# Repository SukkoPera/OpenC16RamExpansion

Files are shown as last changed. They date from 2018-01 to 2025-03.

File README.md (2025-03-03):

# OpenC16RamExpansion
OpenC16RamExpansion is an Open Hardware 64 Kb RAM Expansion board for the Commodore 16.

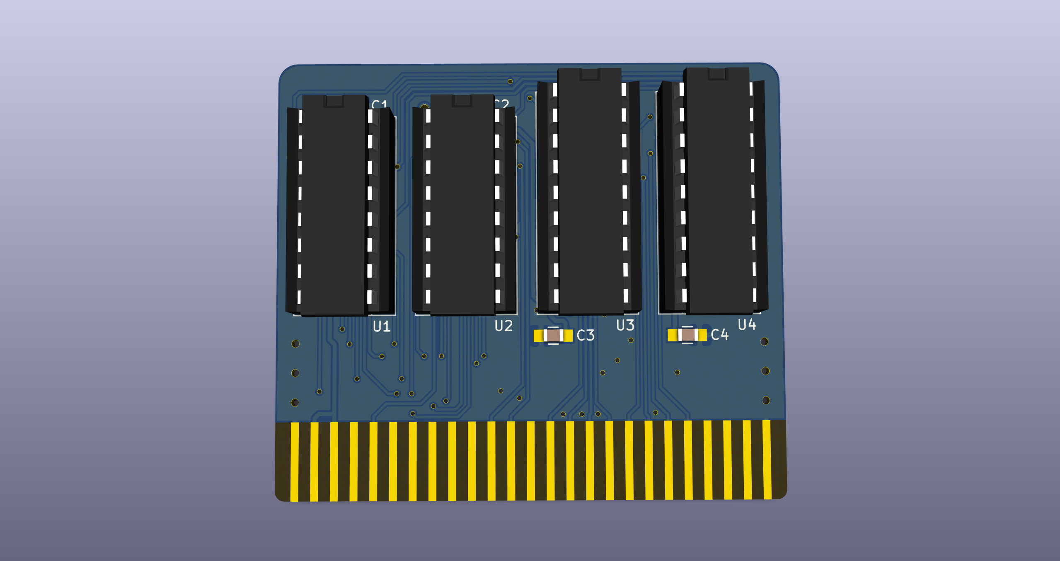
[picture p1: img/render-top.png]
Board


## Summary
The board fits the cartridge/expansion port and, in theory, it should instantly give a C16 64 kilobytes of RAM. Unfortunately, the reality is quite different since the C16 was deliberately designed not to be easily expandable, so that the larger RAM would be a selling point of the Plus/4.

This must have been a long-debated feature, since half of the job is done while the other half is missing. In particular, the /RAS, /CAS and MUX signals that are needed to control RAM chips have been brought to the cartridge slot and these cannot actually serve many other purposes. On the other hand, there is no way to disable the internal RAM when an expansion is plugged in the cartridge slot which means that both RAMs will fight for the bus, amounting to a disasterous effect. 

## So What!?
Old expansions used to come with instructions saying how to disable the internal RAM, which was usually obtained by barbarically cutting the power pins altogether. This had the obvious side effect that at that point the machine could ONLY work with the external expansion plugged in, preventing the use of [other cartridges](https://github.com/SukkoPera/OpenC16Cart) (not that many were made, but what about a [SID Card](https://github.com/SukkoPera/ReSeed) or a [User Port Card](https://github.com/SukkoPera/16up)?).

Other boards had output transistors that would somehow "overpower" the outputs of the internal RAM or - worse - force the internal /RAS signal to a high level.

Since both these things are quite likely to damage the - already precarious - internals of your C16, I didn't even think about replicating them. Instead, I have come up with a not-too-hard modification implementing the missing half of the job that Commodore left to be desired. It can be carried out on all C16s in order to let them work with both the internal or external RAM when plugged in. **If you want to use this Expansion, you will have to perform the following modification**:

1. Disconnect pin 1 of U5 and U6 from the mainboard.
2. Connect pin 13 of U12 to pin 1 of U5 and U6.
3. Blob together pins 11 and 12 of U12.
4. Connect pin Z of the expansion slot to that blob with a wire.
5. Solder a 10k resistor between that blob and pin 14 of U12.

This will disable the internal RAM whenever pin Z on the expansion connector is grounded. This is already done on OpenC16RamExpansion but it should be easy to modify any old cart this way.

Now, if you start up your C16 without any expansion plugged in, it should work as usual and report 12277 bytes free. If you start it up with an expansion, you should get 60671. Actually, this is not yet enough to say that the extra RAM is working properly, since you would get the same even without performing any modification. To make sure it is, enter the following BASIC instructions:

POKE 100, 42
PRINT PEEK 16484

If you get **anything else than 42**, then the expansion is working correctly. If you get 42, it is not (that would mean the "second" 16kB of RAM are a replica of the first 16kB).

If you are using a [LittleSixteen V3 board](https://github.com/SukkoPera/LittleSixteen), there is no need to perform any modification, as it is already built-in.

## Releases
If you want to get this board produced, you are recommended to get [the latest release](https://github.com/SukkoPera/OpenC16RamExpansion/releases) rather than the current git version, as the latter might be under development and is not guaranteed to be working.

Every release is accompanied by its Bill Of Materials (BOM) file and any relevant notes about it, which you are recommended to read carefully.

## License
The OpenC16RamExpansion documentation, including the design itself, is copyright &copy; SukkoPera 2019-2021 and is licensed under the [Creative Commons Attribution-NonCommercial-ShareAlike 4.0 International License](https://creativecommons.org/licenses/by-nc-sa/4.0/).

This documentation is distributed *as is* and WITHOUT ANY EXPRESS OR IMPLIED WARRANTIES whatsoever with respect to its functionality, operability or use, including, without limitation, any implied warranties OF MERCHANTABILITY, SATISFACTORY QUALITY, FITNESS FOR A PARTICULAR PURPOSE or infringement. We expressly disclaim any liability whatsoever for any direct, indirect, consequential, incidental or special damages, including, without limitation, lost revenues, lost profits, losses resulting from business interruption or loss of data, regardless of the form of action or legal theory under which the liability may be asserted, even if advised of the possibility or likelihood of such damages.

## Support the Project
If you want to get some boards manufactured, you can get them from PCBWay through this link:

PCB from PCBWay (https://www.pcbway.com/project/shareproject/OpenC16RamExpansion_V2.html)

You get my gratitude and cheap, professionally-made and good quality PCBs, I get some credit that will help with this and [other projects](https://www.pcbway.com/project/member/shareproject/?bmbid=41100). You won't even have to worry about the various PCB options, it's all pre-configured for you!

Also, if you still have to register, [you can use this link](https://www.pcbway.com/setinvite.aspx?inviteid=41100) to get some bonus initial credit (and yield me some more).

You can also buy me a coffee if you want:

<a href='https://ko-fi.com/L3L0U18L' target='_blank'>Buy Me a Coffee at ko-fi.com</a>

## Credits
This board was laid out only by looking at [various C16/Plus/4 schematics](http://www.zimmers.net/anonftp/pub/cbm/schematics/computers/plus4/index.html) and pictures (mostly low-resolution) of [similar expansions from back in the day](http://plus4world.powweb.com/hardware) I found on the Net, I have never seen one in real life:
* [Rex Speichererweiterung](https://plus4world.powweb.com/hardware/Rex_Speichererweiterung)
* [Jurek's 64K Memory Expansion](https://plus4world.powweb.com/hardware/Jureks_64K_Memory_Expansion)
* [Dela 32K](https://plus4world.powweb.com/hardware/Dela_32K)

So thanks to the makers of those expansions and to Zimmers and Plus/4 World for cataloguing them.

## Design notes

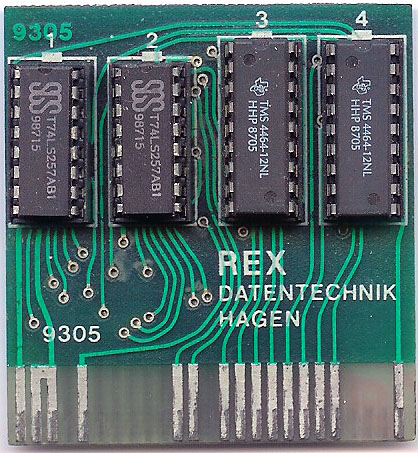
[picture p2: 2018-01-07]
doc/inspiration-1.jpg

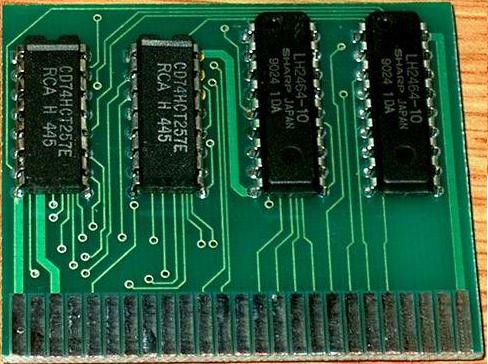
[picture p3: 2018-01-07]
doc/inspiration-2.jpg

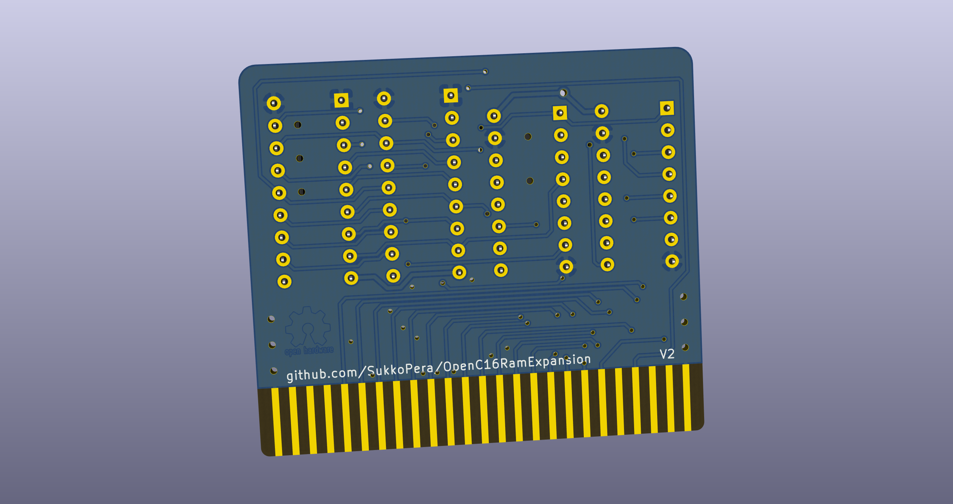
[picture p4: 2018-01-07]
img/render-bottom.png

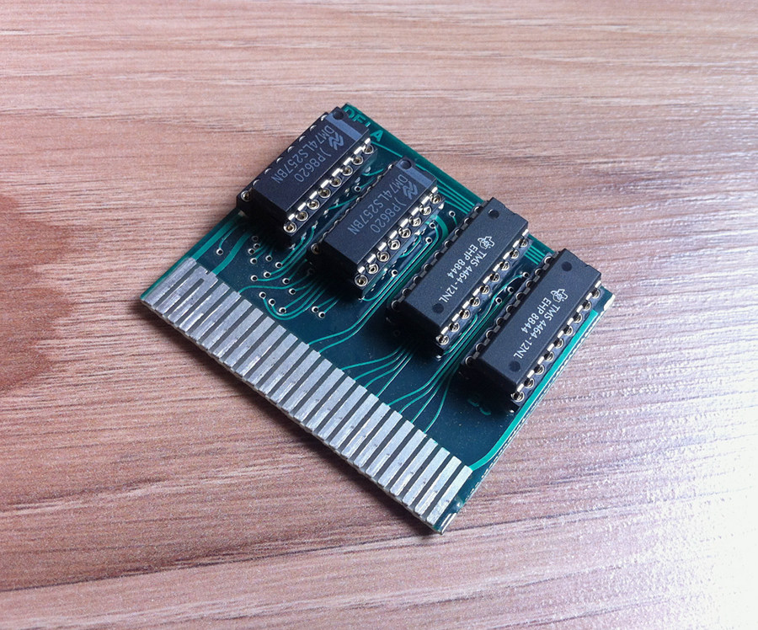
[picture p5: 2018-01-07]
doc/inspiration-3-top.jpg

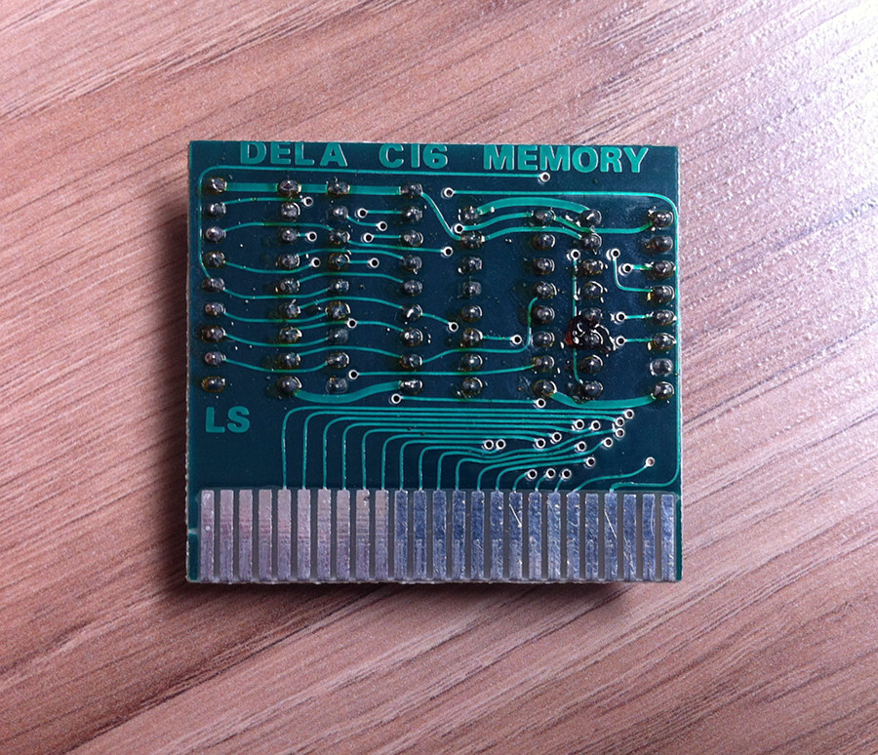
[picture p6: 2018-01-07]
doc/inspiration-3-bottom.jpg

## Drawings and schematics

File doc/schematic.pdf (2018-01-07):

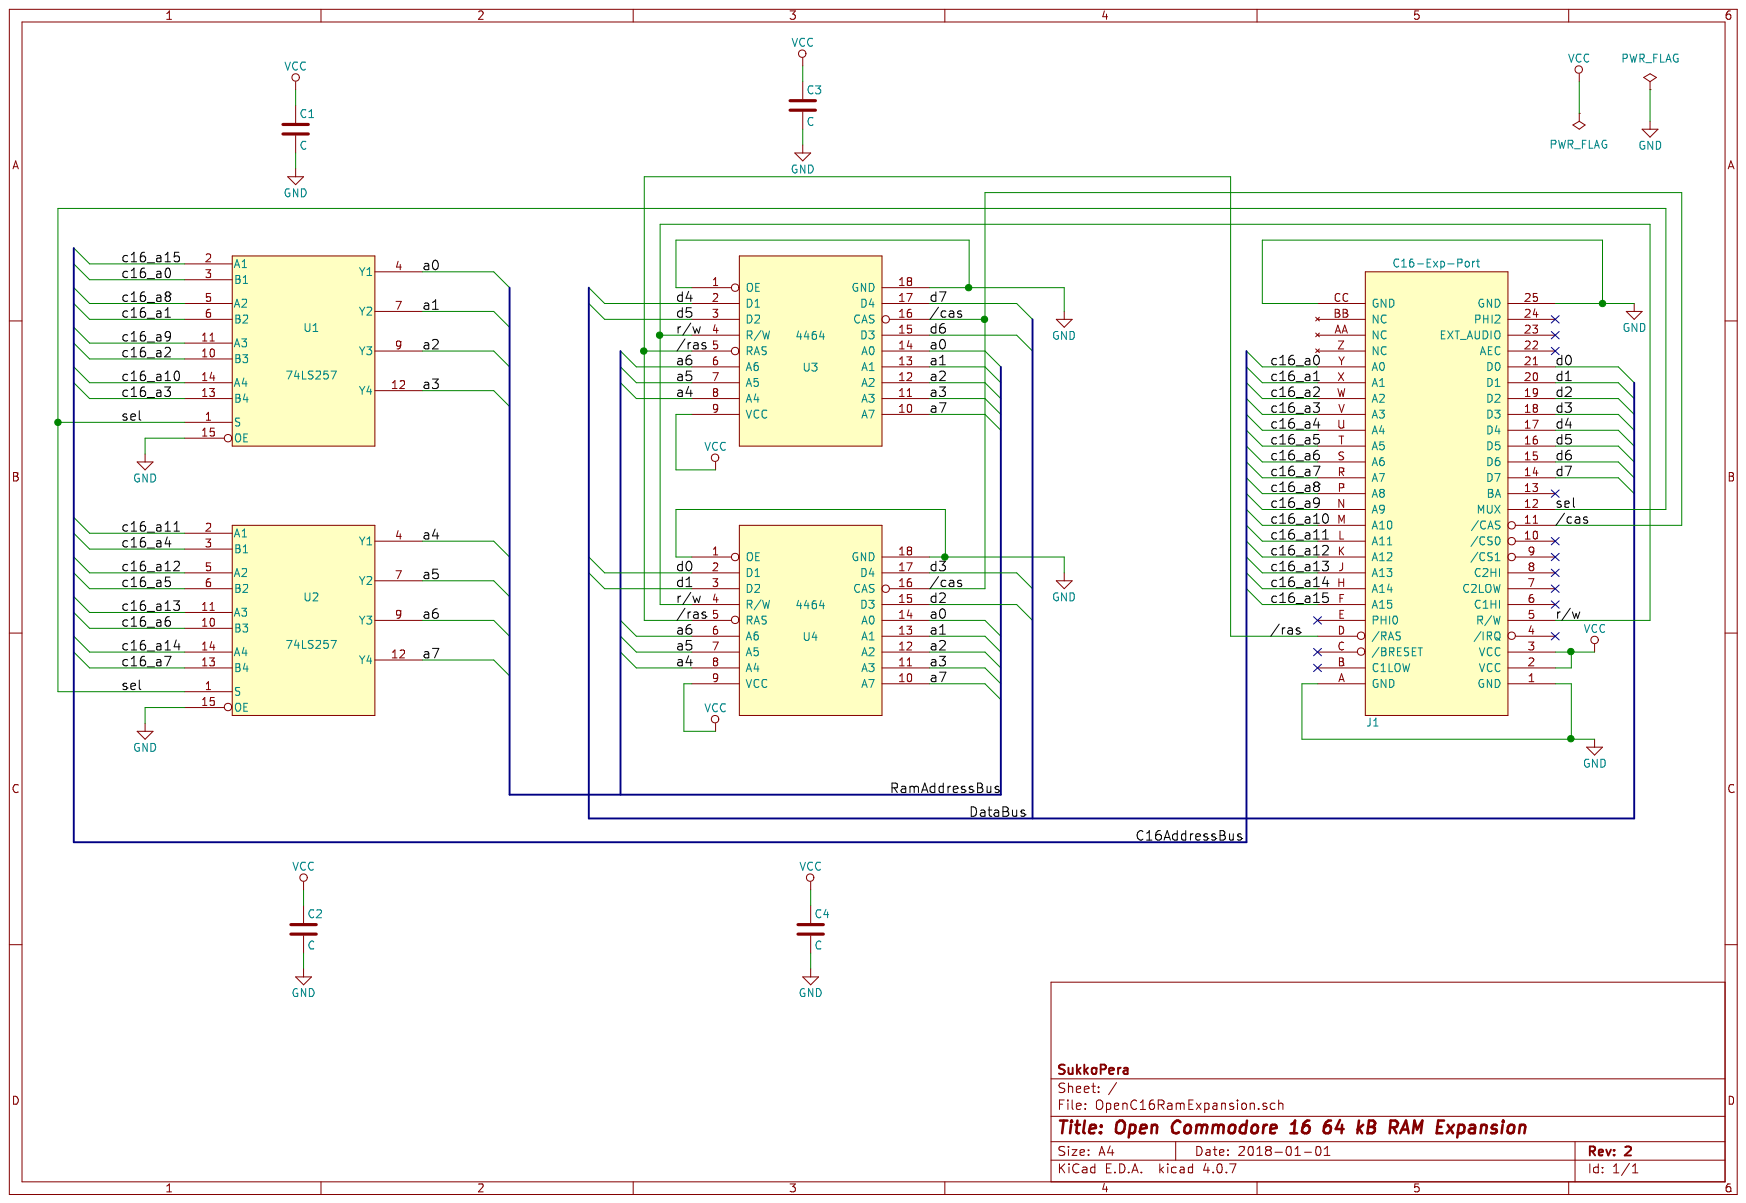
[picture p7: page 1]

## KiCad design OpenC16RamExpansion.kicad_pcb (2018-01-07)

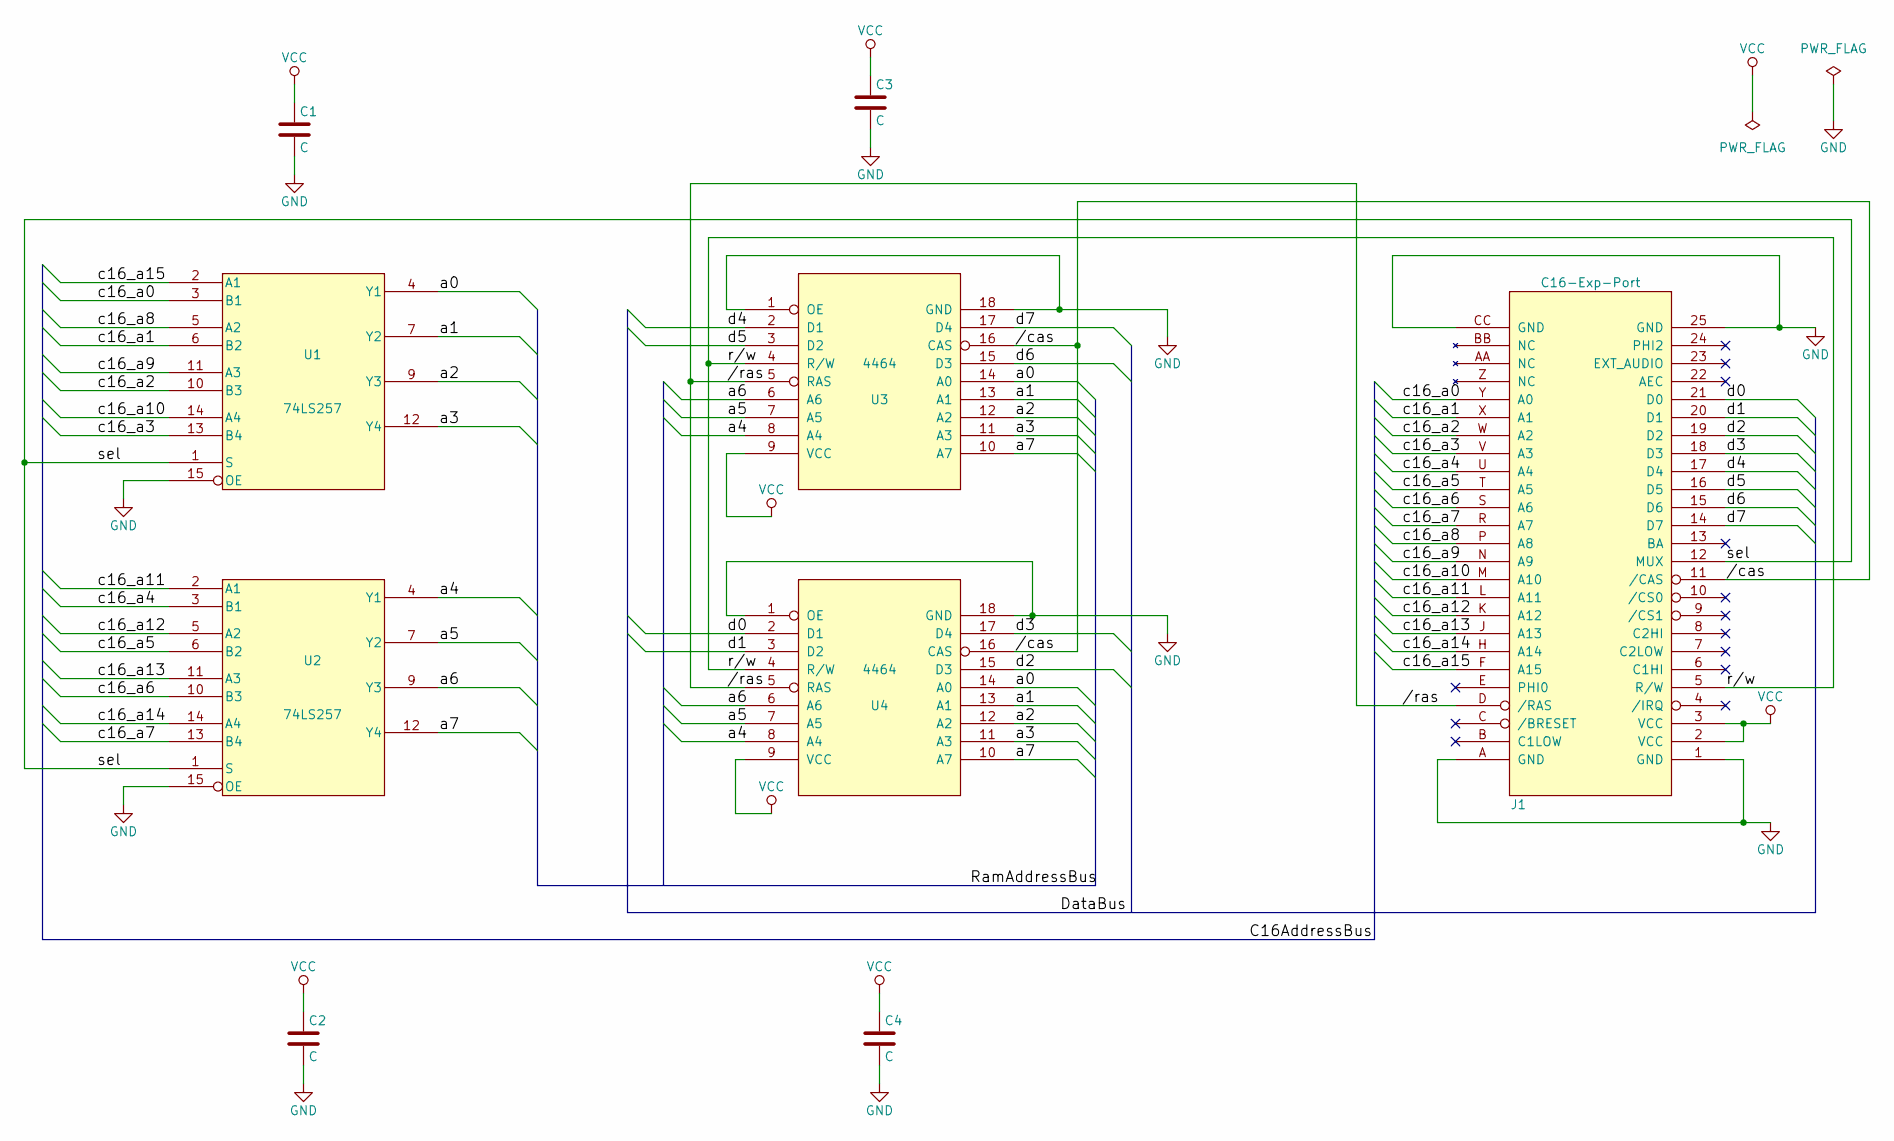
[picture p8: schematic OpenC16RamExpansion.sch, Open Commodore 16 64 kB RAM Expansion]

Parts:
C1, C2, C3, C4: C; C_0805_HandSoldering
J1: C16-Exp-Port; C16_Cart_Conn
U1, U2: 74LS257; DIP-16_W7.62mm_Socket
U3, U4: 4464; DIP-18_W7.62mm_Socket

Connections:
//cas: J1.11 (/CAS), U3.16 (CAS), U4.16 (CAS)
//ras: J1.D (/RAS), U3.5 (RAS), U4.5 (RAS)
/a0: U1.4 (Y1), U3.14 (A0), U4.14 (A0)
/a1: U1.7 (Y2), U3.13 (A1), U4.13 (A1)
/a2: U1.9 (Y3), U3.12 (A2), U4.12 (A2)
/a3: U1.12 (Y4), U3.11 (A3), U4.11 (A3)
/a4: U2.4 (Y1), U3.8 (A4), U4.8 (A4)
/a5: U2.7 (Y2), U3.7 (A5), U4.7 (A5)
/a6: U2.9 (Y3), U3.6 (A6), U4.6 (A6)
/a7: U2.12 (Y4), U3.10 (A7), U4.10 (A7)
/c16_a0: J1.Y (A0), U1.3 (B1)
/c16_a1: J1.X (A1), U1.6 (B2)
/c16_a2: J1.W (A2), U1.10 (B3)
/c16_a3: J1.V (A3), U1.13 (B4)
/c16_a4: J1.U (A4), U2.3 (B1)
/c16_a5: J1.T (A5), U2.6 (B2)
/c16_a6: J1.S (A6), U2.10 (B3)
/c16_a7: J1.R (A7), U2.13 (B4)
/c16_a8: J1.P (A8), U1.5 (A2)
/c16_a9: J1.N (A9), U1.11 (A3)
/c16_a10: J1.M (A10), U1.14 (A4)
/c16_a11: J1.L (A11), U2.2 (A1)
/c16_a12: J1.K (A12), U2.5 (A2)
/c16_a13: J1.J (A13), U2.11 (A3)
/c16_a14: J1.H (A14), U2.14 (A4)
/c16_a15: J1.F (A15), U1.2 (A1)
/d0: J1.21 (D0), U4.2 (D1)
/d1: J1.20 (D1), U4.3 (D2)
/d2: J1.19 (D2), U4.15 (D3)
/d3: J1.18 (D3), U4.17 (D4)
/d4: J1.17 (D4), U3.2 (D1)
/d5: J1.16 (D5), U3.3 (D2)
/d6: J1.15 (D6), U3.15 (D3)
/d7: J1.14 (D7), U3.17 (D4)
/r/w: J1.5 (R/W), U3.4 (R/W), U4.4 (R/W)
/sel: J1.12 (MUX), U1.1 (S), U2.1 (S)
GND: C1.2, C2.2, C3.2, C4.2, J1.1 (GND), J1.25 (GND), J1.A (GND), J1.CC (GND), U1.8 (GND), U1.15 (OE), U2.8 (GND), U2.15 (OE), U3.1 (OE), U3.18 (GND), U4.1 (OE), U4.18 (GND)
VCC: C1.1, C2.1, C3.1, C4.1, J1.2 (VCC), J1.3 (VCC), U1.16 (VCC), U2.16 (VCC), U3.9 (VCC), U4.9 (VCC)

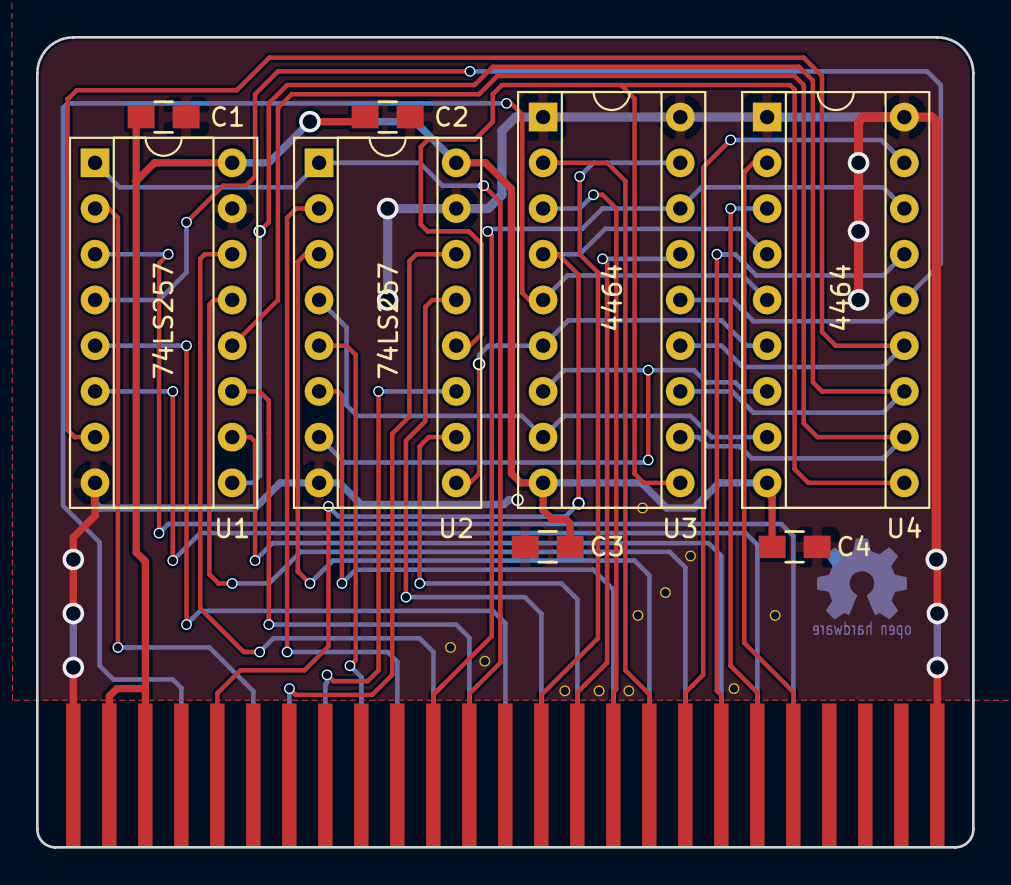
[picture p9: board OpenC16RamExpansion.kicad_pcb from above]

Board: 2 copper layers, 52.0 x 45.0 mm, 9 parts (0 on the bottom side), 38 nets.

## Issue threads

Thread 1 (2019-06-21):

How can this work without disbaling internal ram

mamejay, 2019-06-21:
Hello SukkoPera,
I have made up a cart using your schematic but cannot get it to detect.  On further reading of a few blogs it seems back in the day the original expansion required some hardware mod like cutting the RAS line from the CPU to the ram.
Just wondering how you got yours to work.  I only have a single C16 to test.
Thanks

SukkoPera, 2019-06-21:
Yes, that's the reason why it is stated on the main project page that the expansion does not work on every C16.

Although this means that the expansion is detected correctly but then the memory repeats in 16K chunks. So, if your expansion is NOT detected (i.e.: you get only 12277 bytes free), then your problem is different. Check all traces for continuity and correctness, also check all your solder joints.

Closed 2019-06-21.

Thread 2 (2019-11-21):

Try to get this working on all machines

SukkoPera, 2019-11-21:
AmiBay user eslapion indicates two possible modifications to make this work on all C16's:

>1. The first one is to put a switch on pin 1 (/CE) of the two 4416 of the C16, toggling between ground and 5Vdc - by default they are grounded.
>
> 2. The second one is to use a modified 48 pin socket under the TED which will disconnect CAS from the mainboard and have it on a separate wire going to the 64k RAM cartridge. Just put a pull-up resistor on the 64k RAM cartridge which pulls-up the CAS line of the C16 board.

My opinion:
Solution 1 is well-known but it's not really easy to do, as it requires desoldering the whole chips to get a "clean job".

Solution 2 is more interesting, but I find this would be ok if we wanted to make a board to be sandwiched between the TED and socket, carrying the RAM chips and whatever is needed. An internal expansion that cannot be removed, I mean. This is because **the machine would no longer work if the expansion is unplugged at that point** (unless you also bring out the /CAS signal going to the chips, add a switch and whatever).

The modification I am looking for would ideally be **to add the missing circuitry so that the machine will use the expansion correctly, but so that it will still work correctly if the expansion is unplugged**, without any manual intervention. Ideally, this mod would also be easy to install and it shouldn't require to cut any tracks. But I guess the latter is impossible to achieve, as the whole thing implies the splitting of the /RAS (or /CAS) signal in two, one addressing the internal chips and one going to the cartridge slot. Equations are easy:

```
!ras_int = !ras & (!a14 & !a15) => ras_int = ras | !(!a14 & !a15) => ras_int = ras | a14 | a15
!ras_ext = !ras & (a14 | a15) => ras_ext = ras | !(a14 | a15) => ras_ext = ras | (!a14 & !a15)
```

|ras|a14|a15|**ras_int**|**ras_ext**|
|---|---|---|-----------|-----------|
|0	|0	|0	|0          |1          |
|0	|0	|1	|1          |0          |
|0	|1	|0	|1          |0          |
|0	|1	|1	|1          |0          |
|1	|0	|0	|1          |1          |
|1	|0	|1	|1          |1          |
|1	|1	|0	|1          |1          |
|1	|1	|1	|1          |1          |

The point here is to rewrite these in order to use the least possible logic gates and to make sure that the memory detection routine in the ROM always does the right thing.

I think it can be done with a single [74253](https://www.ti.com/lit/ds/symlink/sn74ls253.pdf) or [4052](https://www.ti.com/lit/ds/symlink/cd4052b.pdf) (Dual 4-TO-1 Multiplexers):

|Pin|74253                        |CD4052B                                     |
|---|-----------------------------|--------------------------------------------|
|1	|/RAS                         |GND                                         |
|2	|a15                          |Vcc                                         |
|3	|Vcc                          |ras_int (with pull-up to Vcc)               |
|4	|Vcc                          |Vcc                                         |
|5	|Vcc                          |Vcc                                         |
|6	|GND                          |/RAS                                        |
|7	|ras_int (with pull-up to Vcc)|GND (power)                                 |
|8	|GND (power)                  |GND (power)                                 |
|9	|ras_ext (with pull-up to Vcc)|a15                                         |
|10	|Vcc                          |a14                                         |
|11	|GND                          |GND                                         |
|12	|GND                          |Vcc                                         |
|13	|GND                          |ras_ext (with pull-up to Vcc)               |
|14	|a14                          |GND                                         |
|15	|/RAS                         |GND                                         |
|16	|Vcc (power)                  |Vcc (power)                                 |

Another possibility is [here](https://plus4world.powweb.com/forum/38842).

SukkoPera, 2025-03-01:
After a few years, I think this makes no sense...

Closed 2025-03-01.

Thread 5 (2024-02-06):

C116??

Flocke28, 2024-02-06:
Hi.. I got this on eBay with info it works for C116 also.. but in the description i can’t see any info about C116.. the IC Numbers don’t match on the C116. Do you have additional info? It don’t work without any hacks

SukkoPera, 2024-02-06:
I know I'll sound harsh but I'm tired of people making money with my projects and never contributing back, neither technically nor economically and relying on me for free support.

So please ask the seller for support, he got the money, he's in charge of that.

Closed 2024-02-06.

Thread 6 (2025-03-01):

A mistake in description for HW changes.

a-lex-z, 2025-03-01:
Please correct in the Readme following part:

> 5. Blob together pins 12 and 13 of U12.

to **Blob together pins 12 and 11 of U12.**

SukkoPera, 2025-03-01:
Thanks for the report! I think you are correct, did you test it?

a-lex-z, 2025-03-01:
I haven't test it yet, but it must work.
In your case, when pin 12 connected with pin 13, it's definitely incorrect, because output of the logic element is connected to input.
Please refer to LittleSixteen V3 schematics and see how it implemented there.

SukkoPera, 2025-03-02:
OK, thanks.

SukkoPera, 2025-03-03:
Fixed, please have a look at the new instructions.

Closed 2025-03-03.

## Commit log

2017-08-20 Initial commit - WORK IN PROGRESS!
    [OpenC16RamExpansion.kicad_pcb, OpenC16RamExpansion.sch]
2017-08-20 Add Expansion Port symbol and footprint
2017-08-21 Complete schematics
    [OpenC16RamExpansion.sch]
2017-08-21 Working on PCB
    [OpenC16RamExpansion.kicad_pcb]
2017-08-23 Almost there...
    [OpenC16RamExpansion.kicad_pcb, OpenC16RamExpansion.sch]
2017-08-23 Make connector footprint larger and taller
2017-08-23 Switch to new connector and improve back ground plane
    [OpenC16RamExpansion.kicad_pcb]
2017-09-02 Make connector lower again and smooth orners
    [OpenC16RamExpansion.kicad_pcb]
2017-09-02 Add decoupling caps
    [OpenC16RamExpansion.kicad_pcb, OpenC16RamExpansion.sch]
2017-09-29 Make board 0.5mm wider and space edge contacts 2.00 apart
    [OpenC16RamExpansion.kicad_pcb]
2017-09-29 Smooth top corners Radius is 2mm. Bottom is 1.5mm
    [OpenC16RamExpansion.kicad_pcb]
2017-09-29 Zero pad clearance
    [OpenC16RamExpansion.kicad_pcb]
2017-09-29 Reduce antipad clearance
    [OpenC16RamExpansion.kicad_pcb]
2017-09-29 Bump version
    [OpenC16RamExpansion.kicad_pcb]
2017-09-29 Fix 3D models
    [OpenC16RamExpansion.kicad_pcb]
2018-01-01 Space edge connector pins 2.0mm apart, improve ground plane and some other tweaks
    [OpenC16RamExpansion.kicad_pcb, OpenC16RamExpansion.sch]
2018-01-01 Make board slightly larger
    [OpenC16RamExpansion.kicad_pcb]
2018-01-07 Final touches for V2
    [OpenC16RamExpansion.kicad_pcb]
